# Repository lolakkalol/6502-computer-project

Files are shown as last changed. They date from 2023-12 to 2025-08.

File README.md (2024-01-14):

<!-- Improved compatibility of back to top link: See: https://github.com/lolakkalol/6502-computer-project/pull/73 -->

<!--
*** Thanks for checking out the Best-README-Template. If you have a suggestion
*** that would make this better, please fork the repo and create a pull request
*** or simply open an issue with the tag "enhancement".
*** Don't forget to give the project a star!
*** Thanks again! Now go create something AMAZING! :D
-->

<!-- PROJECT SHIELDS -->
<!--
*** I'm using markdown "reference style" links for readability.
*** Reference links are enclosed in brackets [ ] instead of parentheses ( ).
*** See the bottom of this document for the declaration of the reference variables
*** for contributors-url, forks-url, etc. This is an optional, concise syntax you may use.
*** https://www.markdownguide.org/basic-syntax/#reference-style-links
-->
[][contributors-url]
[][forks-url]
[][stars-url]
[][issues-url]
<!--[![MIT License][license-shield]][license-url]
[![LinkedIn][linkedin-shield]][linkedin-url]-->

<!-- PROJECT LOGO -->
<br />
<div align="center">
  <a href="https://github.com/lolakkalol/6502-computer-project">
    
  </a>

  <h3 align="center">6502 Computer Project</h3>

  <p align="center">
    A 6502-based computer project!
    <br />
    <a href="https://github.com/lolakkalol/6502-computer-project"><strong>Explore the docs »</strong></a>
    <br />
    <br />
    <a href="https://github.com/lolakkalol/6502-computer-project/tree/main/programs">View Demo Programs</a>
    ·
    <a href="https://github.com/lolakkalol/6502-computer-project/issues">Report Bug</a>
    ·
    <a href="https://github.com/lolakkalol/6502-computer-project/issues">Request Feature</a>
  </p>
</div>

<!-- TABLE OF CONTENTS -->
<details>
  <summary>Table of Contents</summary>
  <ol>
    <li>
      <a href="#about-the-project">About The Project</a>
      <ul>
        <li><a href="#built-with">Built With</a></li>
      </ul>
    </li>
    <li>
      <a href="#getting-started">Getting Started</a>
      <ul>
        <li><a href="#prerequisites">Prerequisites</a></li>
        <li><a href="#installation">Installation</a></li>
      </ul>
    </li>
    <li><a href="#usage">Usage</a></li>
    <li><a href="#roadmap">Roadmap</a></li>
    <li><a href="#contributing">Contributing</a></li>
    <li><a href="#license">License</a></li>
    <li><a href="#contact">Contact</a></li>
    <li><a href="#acknowledgments">Acknowledgments</a></li>
  </ol>
</details>

<!-- ABOUT THE PROJECT -->
## About The Project

[Product Name Screen Shot](https://example.com)

This project started thanks to [Ben Eater's](https://www.youtube.com/@BenEater) video series on his 6502-based computer, which is the basis for my project and learning experience.
The project has a very simple goal of me learning low-level embedded system development on hardware and software. To achieve this learning goal, a few project goals/milestones have been set up to steer the project in a satisfactory direction.
The computer should also not be a carbon copy of Ben Eater's computer to promote self-learning and delving into documentation and learning by doing. I believe you remember things better when you fail at something and, in the end, solve the problems that made you fail.

### Goals
These goals aim to create a 6502-based computer on a single PCB that can be expanded with modules later on.
- Learn "low-level" embedded computer architecture basics
  - Both hardware and software
- Build a 6502-based computer on a PCB which shall:
  - Be expandable, meaning you can add modules to it later (Some kind of expansion bus)
  - Output text console to a computer screen
  - Handle mouse and keyboard (USB/PS2 either or both)
  - Have serial communication capability
  - Load programs over serial into RAM (Maybe some kind of bootloader?)
  - Flash the program flash over some protocol
  - Some kind of operating system
- Try and avoid scope creep
- HAVE FUN!

<p align="right">(<a href="#readme-top">back to top</a>)</p>

### Built With
These are the currently used programs and frameworks used for building the project, for both software and hardware.

- [CA65, LD65](https://cc65.github.io/) for assembling, linking and relocating the code.
- [KiCad](https://www.kicad.org/) for designing the computer and its physical layout.
- [GNU Make](https://www.gnu.org/software/make/) for automating the build tasks of CC65 and LD65.

<p align="right">(<a href="#readme-top">back to top</a>)</p>

<!-- GETTING STARTED -->
## Getting Started

To get a local copy up and running follow these simple example steps.

### Prerequisites

* CC65 (Windows/Linux)
Download and install the cross-development package [CC65](https://github.com/cc65/cc65) (available for both Windows and Linux).

* GNU Utils (Windows)
Download `GNU make` and `CoreUtils` from https://gnuwin32.sourceforge.net/packages.html and add them to your path.

### Installation (Software)

1. Clone the repository
2. In `6502-computer-project/programs/<program name>/` simple run make
3. Flash the EEPROM using your choice of programmer

<p align="right">(<a href="#readme-top">back to top</a>)</p>

<!-- USAGE EXAMPLES -->
## Usage

This project currently has three different areas: Schematics and KiCad symbols, hardware debugger, and programs, each will be explained below.

### Schematics and KiCad symbols
Found in the folder `6502-and-friends` and `6502-schematic`, here the schematic over the computer, the custom symbols and PCB design can be found.

### Hardware debugger
Found, at the moment, in the folder `bus-sniffer`; this is simply a program for an Arduino Mega2560 sniffing and printing to the console the: Address bus, data buss and control bus.
It can also supply its own clock, which can be halted at the press of a button and send single clock pulses to support hardware debugging.

### Programs
Found in the folder `Programs`, contain all the currently constructed programs and a template for creating a new program.
Each program comes with its own make file specifying how it is to be built together with throughout commenting. 
All programs are written in 6502 assembly and most is created according to the specified template.

The template contain the following:
- `main.asm` Here is the main code.
- `lib.asm` Here, the supporting code should be put, such as sub-routines, following the example sub-routines structure.
- `start.asm` holds the start-up code and is already written in the template; it is responsible for initializing memory segments at startup.
- `makefile` Specifies how to build and link `main.asm`, `lib.asm` and `start.asm`.
- `target.cfg` Specifies the address space, segments, and their location in memory for the linker to us.

<p align="right">(<a href="#readme-top">back to top</a>)</p>

<!-- ROADMAP -->
## Roadmap
There are currently two main roadmaps, one for a Pi estimation program used to get familiar with the 6502 and another for the actual computer project.
For the Pi estimation program the computer seen in the current KiCad schematic is used.

### Pi estimation
- [ ] IEEE 754 Floating point arithmetic
  - [X] Addition/Subtraction
  - [ ] Multiplication
  - [ ] Division
  - [ ] (To be expanded upon if necessary)
- [ ] LCD printing
- [ ] Convert Floating point numbers to decimal
- [ ] Pi estimation algorithm
  - [ ] (To be expanded upon)

### 6502-based computer
- [ ] Decide desirable features
- [ ] Design schematic
  - [ ] Research chips needed
  - [ ] Plan address space
  - [ ] Create KiCad symbols for chips
  - [ ] Route connections between chips
  - [ ] (To be expanded upon)
- [ ] Operating system?

See the [open issues](https://github.com/lolakkalol/6502-computer-project/issues) for a full list of proposed features (and known issues).

<p align="right">(<a href="#readme-top">back to top</a>)</p>

## Micro documentation
Here a very small condenced documentation can be found only used as a quick reference.
The code is often commented so do not forget to look there.

### Memory map


### Floating point routines
The floating point routines are all commented on and explained in the code but have also been planned before implementation using a high-level flowchart in draw.io found below.

[Flowchart](https://drive.google.com/file/d/1zk0GJeMiMwG2__90PIV5DE1KcaoCTDiV/view?usp=sharing)

<!-- CONTRIBUTING -->
<!--## Contributing

Contributions are what make the open source community such an amazing place to learn, inspire, and create. Any contributions you make are **greatly appreciated**.

If you have a suggestion that would make this better, please fork the repo and create a pull request. You can also simply open an issue with the tag "enhancement".
Don't forget to give the project a star! Thanks again!

1. Fork the Project
2. Create your Feature Branch (`git checkout -b feature/AmazingFeature`)
3. Commit your Changes (`git commit -m 'Add some AmazingFeature'`)
4. Push to the Branch (`git push origin feature/AmazingFeature`)
5. Open a Pull Request

<p align="right">(<a href="#readme-top">back to top</a>)</p>-->

<!-- LICENSE -->
<!--## License

Distributed under the MIT License. See `LICENSE.txt` for more information.

<p align="right">(<a href="#readme-top">back to top</a>)</p>-->

<!-- CONTACT -->
## Contact

Alexander Stenlund -  alexander.stenlund@telia.com

Project Link: [https://github.com/lolakkalol/6502-computer-project](https://github.com/lolakkalol/6502-computer-project)

<p align="right">(<a href="#readme-top">back to top</a>)</p>

<!-- ACKNOWLEDGMENTS -->
## Acknowledgments

* [6502 Primer](https://wilsonminesco.com/6502primer/)
* [6502 forum](http://forum.6502.org/viewtopic.php?t=1064&start=105)
* [65SIB](http://forum.6502.org/viewtopic.php?t=1064&start=105)

<p align="right">(<a href="#readme-top">back to top</a>)</p>

<!-- MARKDOWN LINKS & IMAGES -->
<!-- https://www.markdownguide.org/basic-syntax/#reference-style-links -->
[contributors-shield]: https://img.shields.io/github/contributors/lolakkalol/6502-computer-project.svg?style=for-the-badge
[contributors-url]: https://github.com/lolakkalol/6502-computer-project/graphs/contributors
[forks-shield]: https://img.shields.io/github/forks/lolakkalol/6502-computer-project.svg?style=for-the-badge
[forks-url]: https://github.com/lolakkalol/6502-computer-project/network/members
[stars-shield]: https://img.shields.io/github/stars/lolakkalol/6502-computer-project.svg?style=for-the-badge
[stars-url]: https://github.com/lolakkalol/6502-computer-project/stargazers
[issues-shield]: https://img.shields.io/github/issues/lolakkalol/6502-computer-project.svg?style=for-the-badge
[issues-url]: https://github.com/lolakkalol/6502-computer-project/issues
[license-shield]: https://img.shields.io/github/license/lolakkalol/6502-computer-project.svg?style=for-the-badge
[license-url]: https://github.com/lolakkalol/6502-computer-project/blob/master/LICENSE.txt
[linkedin-shield]: https://img.shields.io/badge/-LinkedIn-black.svg?style=for-the-badge&logo=linkedin&colorB=555
[linkedin-url]: https://linkedin.com/in/othneildrew
[product-screenshot]: images/screenshot.png

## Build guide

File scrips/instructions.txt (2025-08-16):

ADC #Oper;69
ADC (ZP);72
ADC (ZP),Y;71
ADC (ZP,X);61
ADC Abs;6D
ADC Abs,X;7D
ADC Abs,Y;79
ADC ZP;65
ADC ZP,X;75
AND #Oper;29
AND (ZP);32
AND (ZP),Y;31
AND (ZP,X);21
AND Abs;2D
AND Abs,X;3D
AND Abs,Y;39
AND ZP;25
AND ZP,X;35
ASL A;0A
ASL Abs;0E
ASL Abs,X;1E
ASL ZP;6
ASL ZP,X;16
BBR0 Oper;0F
BBR1 Oper;1F
BBR2 Oper;2F
BBR3 Oper;3F
BBR4 Oper;4F
BBR5 Oper;5F
BBR6 Oper;6F
BBR7 Oper;7F
BBS0 Oper;8F
BBS1 Oper;9F
BBS2 Oper;AF
BBS3 Oper;BF
BBS4 Oper;CF
BBS5 Oper;DF
BBS6 Oper;EF
BBS7 Oper;FF
BCC Oper;90
BCS Oper;B0
BEQ Oper;F0
BIT #Oper;89
BIT Abs;2C
BIT Abs,X;3C
BIT ZP;24
BIT ZP,X;34
BMI Oper;30
BNE Oper;D0
BPL Oper;10
BRA Oper;80
BRK;0
BVC Oper;50
BVS Oper;70
CLC;18
CLD;D8
CLI;58
CLV;B8
CMP #Oper;C9
CMP (ZP);D2
CMP (ZP),Y;D1
CMP (ZP,X);C1
CMP Abs;CD
CMP Abs,X;DD
CMP Abs,Y;D9
CMP ZP;C5
CMP ZP;D5
CPX #Oper;E0
CPX Abs;EC
CPX ZP;E4
CPY #Oper;C0
CPY Abs;CC
CPY ZP;C4
DEA;3A
DEC Abs;CE
DEC Abs,X;DE
DEC ZP;C6
DEC ZP,X;D6
DEX;CA
DEY;88
EOR #Oper;49
EOR (ZP);52
EOR (ZP),Y;51
EOR (ZP,X);41
EOR Abs;4D
EOR Abs,X;5D
EOR Abs,Y;59
EOR ZP;45
EOR ZP,X;55
INA;1A
INC Abs;EE
INC Abs,X;FE
INC ZP;E6
INC ZP,X;F6
INX;E8
INY;C8
JMP (Abs);6C
JMP (Abs,X);7C
JMP Abs;4C
JSR Abs;20
LDA #Oper;A9
LDA (ZP);B2
LDA (ZP),Y;B1
LDA (ZP,X);A1
LDA Abs;AD
LDA Abs,X;BD
LDA Abs,Y;B9
LDA ZP;A5
LDA ZP,X;B5
LDX #Oper;A2
LDX Abs;AE
LDX Abs,Y;BE
LDX ZP;A6
LDX ZP,Y;B6
LDY #Oper;A0
LDY Abs;AC
LDY Abs,X;BC
LDY ZP;A4
LDY ZP,X;B4
LSR A;4A
LSR Abs;4E
LSR Abs,X;5E
LSR ZP;46
LSR ZP,X;56
NOP;EA
ORA #Oper;9
ORA (ZP);12
ORA (ZP),Y;11
ORA (ZP,X);1
ORA Abs;0D
ORA Abs,X;1D
ORA Abs,Y;19
ORA ZP;5
ORA ZP,X;15
PHA;48
PHX;DA
PHY;5A
PLA;68
PLX;FA
PLY;7A
ROL A;2A
ROL Abs;2E
ROL Abs,X;3E
ROL ZP;26
ROL ZP,X;36
ROR A;6A
ROR Abs;6E
ROR Abs,X;7E
ROR ZP;66
ROR ZP,X;76
RTI;40
RTS;60
SBC #Oper;E9
SBC (ZP);F2
SBC (ZP),Y;F1
SBC (ZP,X);E1
SBC Abs;ED
SBC Abs,X;FD
SBC Abs,Y;F9
SBC ZP;E5
SBC ZP,X;F5
SEC;38
SED;F8
SEI;78
STA (ZP);92
STA (ZP),Y;91
STA (ZP,X);81
STA Abs;8D
STA Abs,X;9D
STA Abs,Y;99
STA ZP;85
STA ZP,X;95
STX Abs;8E
STX ZP;86
STX ZP,Y;96
STY Abs;8C
STY ZP;84
STY ZP,X;94
STZ Abs;9C
STZ Abs,X;9E
STZ ZP;64
STZ ZP,X;74
TAX;AA
TAY;A8
TRB Abs;1C
TRB ZP;14
TSB Abs;0C
TSB ZP;4
TSX;BA
TXA;8A
TXS;9A
TYA;98

case 0x$1:
    sprintf(buf, "$2");
    break;

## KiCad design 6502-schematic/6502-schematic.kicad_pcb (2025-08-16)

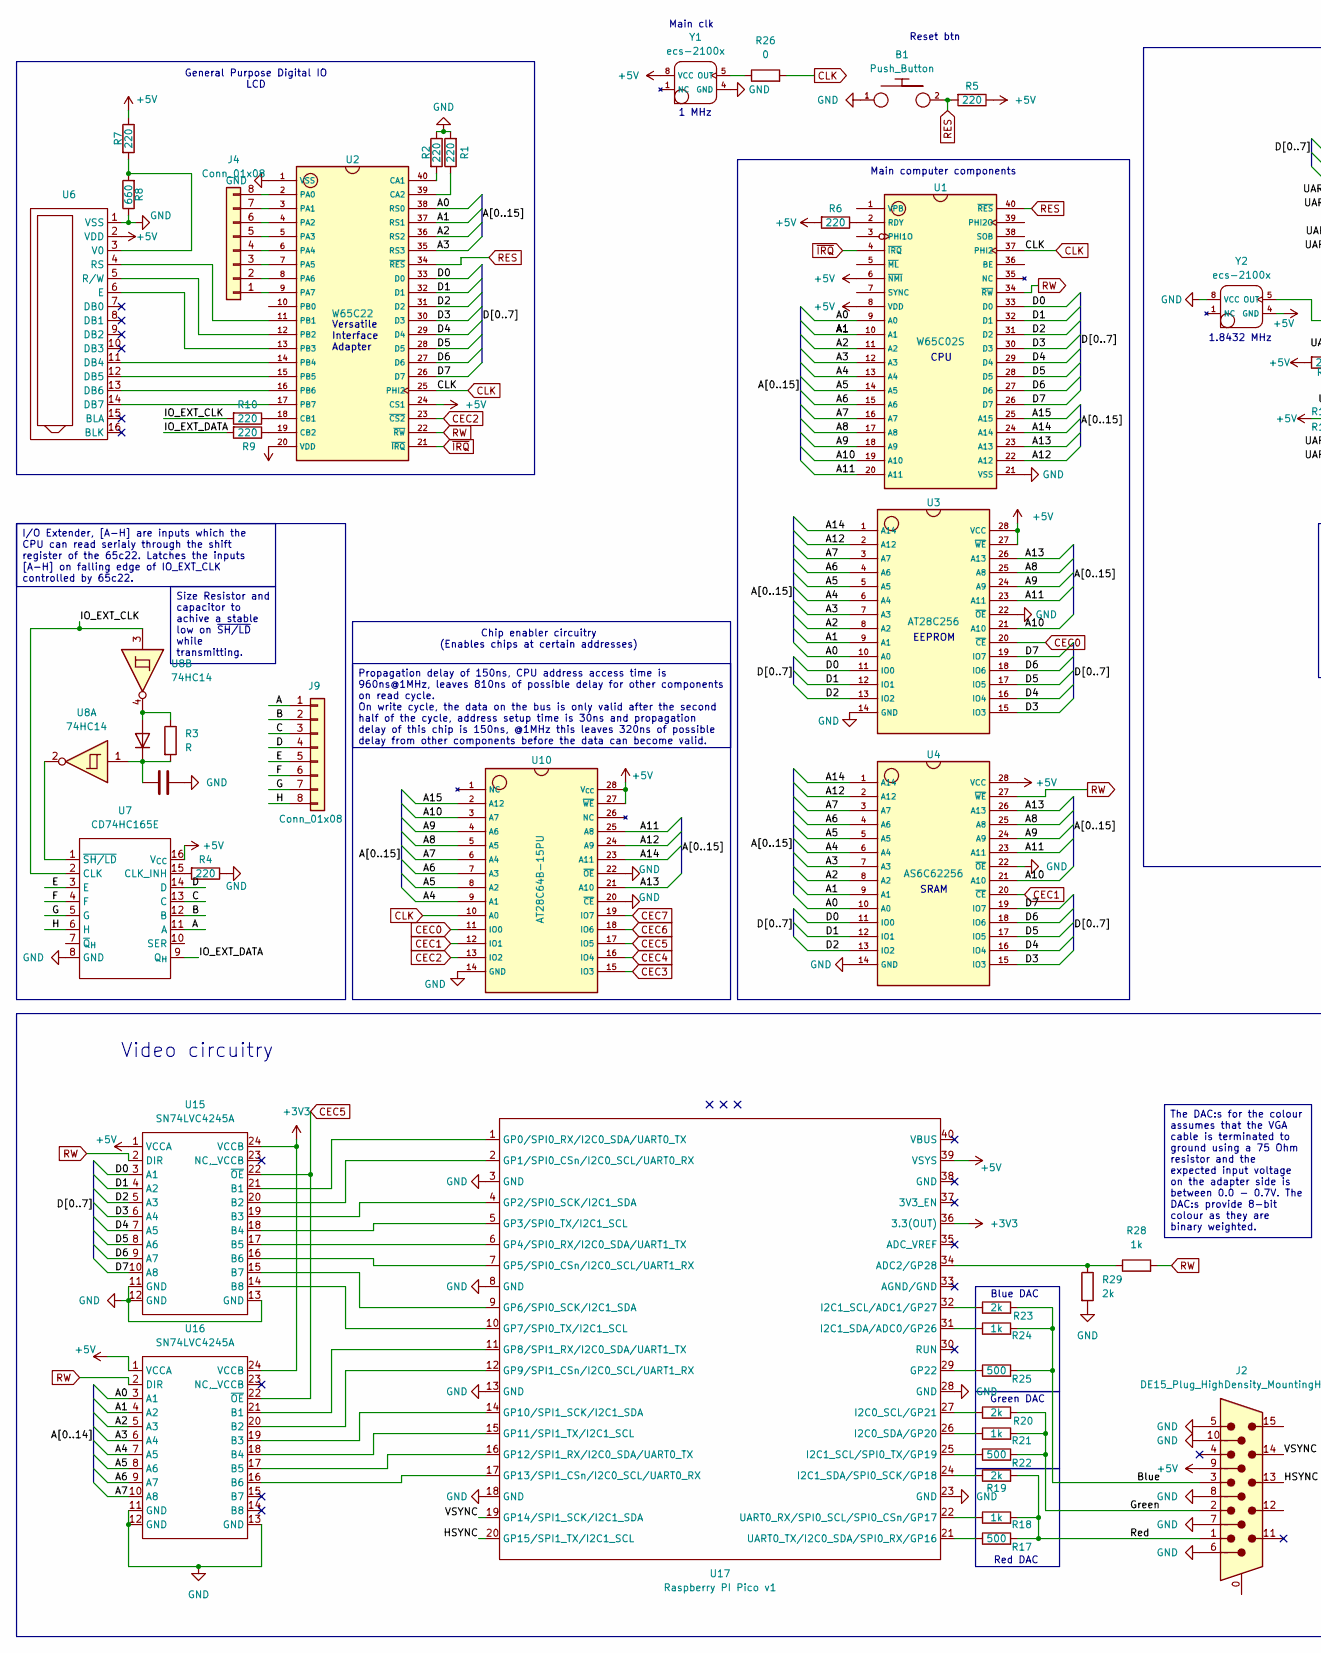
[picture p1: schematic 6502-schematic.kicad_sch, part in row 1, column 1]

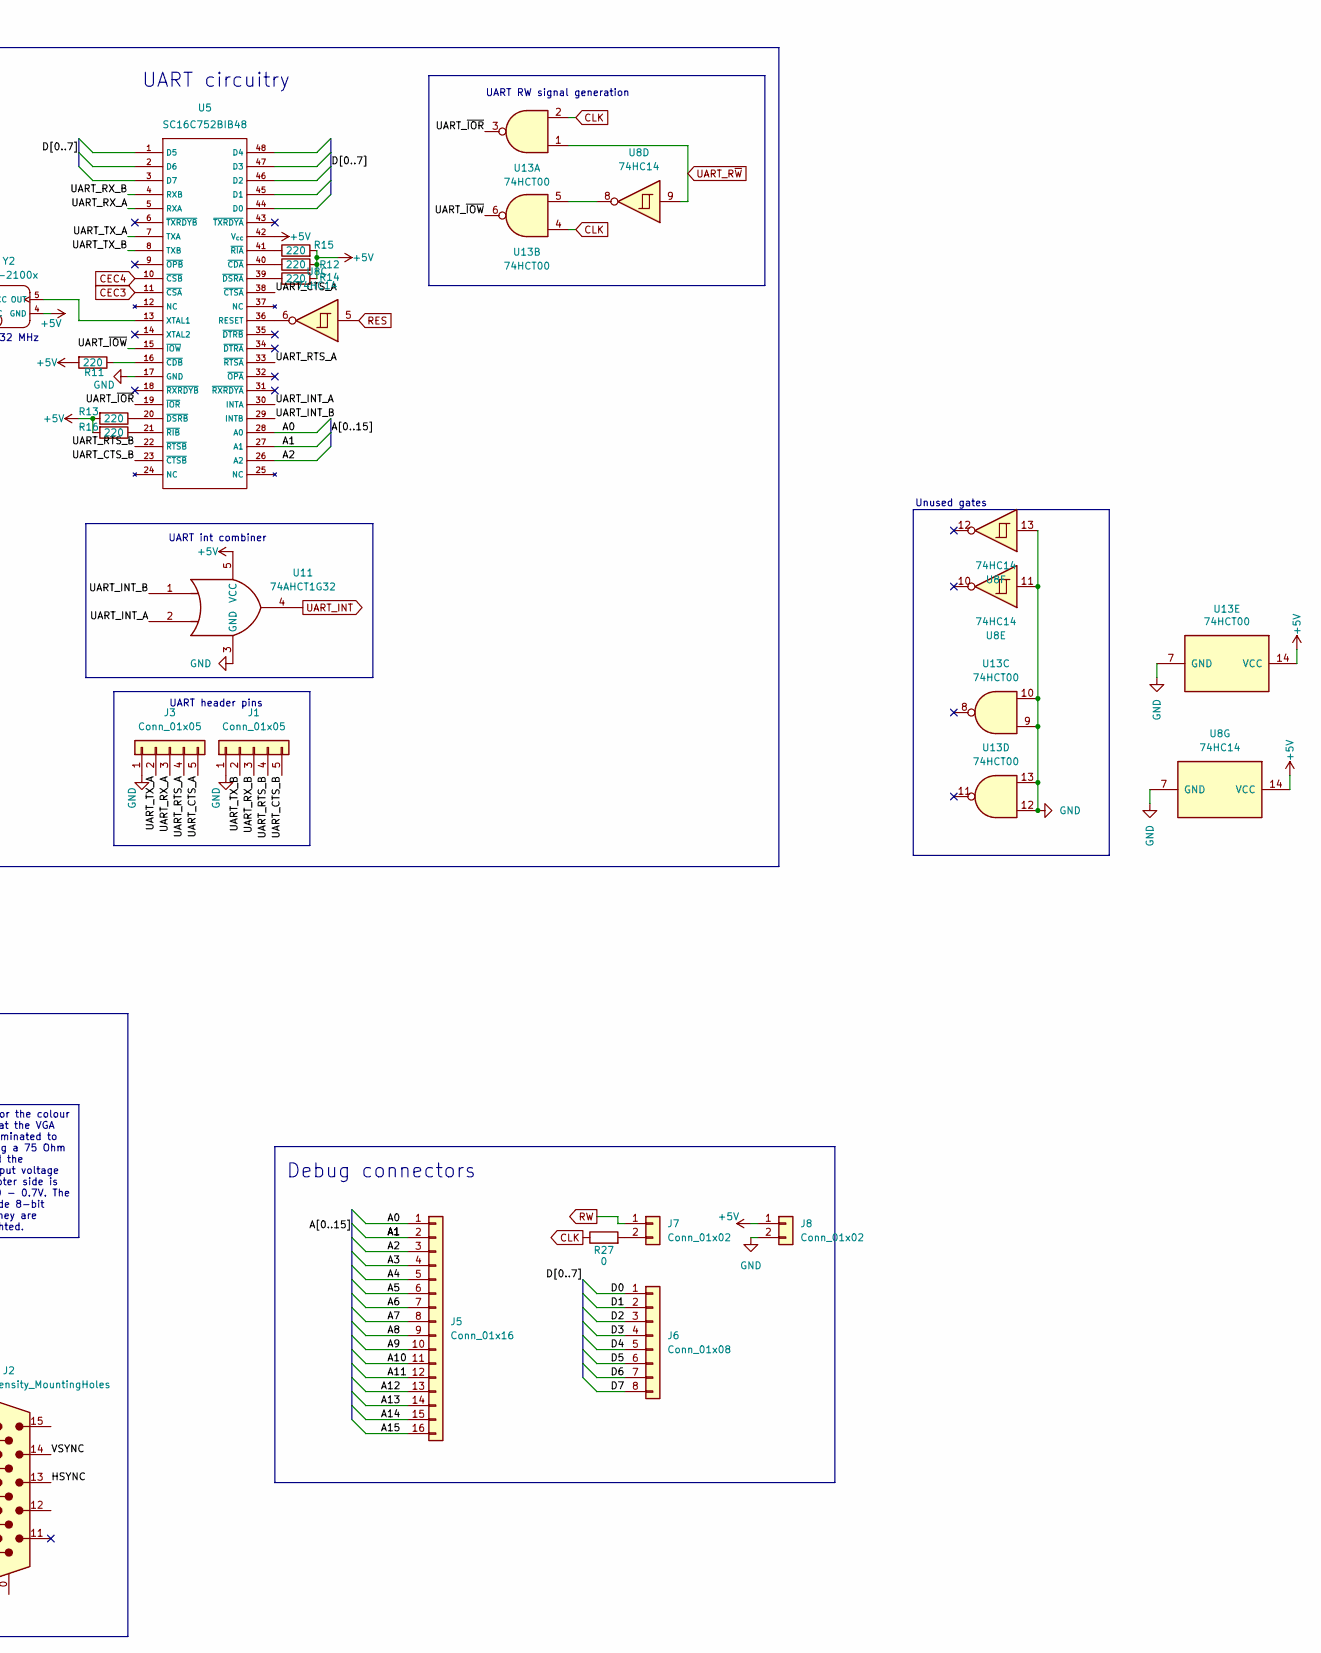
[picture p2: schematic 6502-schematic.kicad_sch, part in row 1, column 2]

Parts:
B1: Push_Button; KSA_Tactile_SPST
C1: C; C_Disc_D9.0mm_W5.0mm_P10.00mm
D1: D; D_5W_P10.16mm_Horizontal
J1, J3: Conn_01x05; PinHeader_1x05_P2.54mm_Vertical
J2: DE15_Plug_HighDensity_MountingHoles; PinHeader_2x08_P2.54mm_Vertical
J4, J6, J9: Conn_01x08; PinHeader_1x08_P2.54mm_Vertical
J5: Conn_01x16; PinHeader_1x16_P2.54mm_Vertical
J7, J8: Conn_01x02; PinHeader_1x02_P2.54mm_Vertical
R1, R2, R4, R5, R6, R7, R9, R10, R11, R12, R13, R14, R15, R16: 220; R_Axial_DIN0204_L3.6mm_D1.6mm_P2.54mm_Vertical
R3: R; R_Axial_DIN0204_L3.6mm_D1.6mm_P2.54mm_Vertical
R8: 660; R_Axial_DIN0204_L3.6mm_D1.6mm_P2.54mm_Vertical
R17, R22, R25: 500; R_Axial_DIN0204_L3.6mm_D1.6mm_P2.54mm_Vertical
R18, R21, R24, R28: 1k; R_Axial_DIN0204_L3.6mm_D1.6mm_P2.54mm_Vertical
R19, R20, R23, R29: 2k; R_Axial_DIN0204_L3.6mm_D1.6mm_P2.54mm_Vertical
R26, R27: 0; R_0805_2012Metric_Pad1.20x1.40mm_HandSolder
U1: W65C02S; DIP-40_W15.24mm_LongPads
U2: W65C22; DIP-40_W15.24mm_LongPads
U3: AT28C256; DIP-28_W15.24mm_LongPads
U4: AS6C62256; DIP-28_W15.24mm_LongPads
U5: SC16C752BIB48; LQFP-48_7x7mm_P0.5mm
U6: PinHeader_1x16_P2.54mm_Vertical
U7: CD74HC165E; DIP-16_W7.62mm_LongPads
U8: 74HC14; CERDIP-14_W7.62mm_SideBrazed_LongPads
U10: AT28C64B-15PU; DIP-28_W15.24mm_LongPads
U11: 74AHCT1G32; SOT-23-5_HandSoldering
U13: 74HCT00; DIP-14_W7.62mm_LongPads
U15, U16: SN74LVC4245A; SOIC-24W_7.5x15.4mm_P1.27mm
U17: Raspberry PI Pico v1; Raspberry_PI_Pico_Socket
Y1, Y2: ecs-2100x; ECS-2100X

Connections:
+3V3: U15.24 (VCCB), U16.24 (VCCB), U17.36 (3.3(OUT))
+5V: J2.9, J8.1, R5.1, R6.2, R7.1, R11.2, R12.2, R13.2, R14.2, R15.2, R16.2, U1.6 (~NMI), U1.8 (VDD), U2.20 (VDD), U2.24 (CS1), U3.27 (~WE), U3.28 (VCC), U4.28 (VCC), U5.42 (V_{cc}), U6.2 (VDD), U7.16 (V_{CC}), U8.14 (VCC), U10.27 (~WE), U10.28 (V_{CC}), U11.5 (VCC), U13.14 (VCC), U15.1 (VCCA), U16.1 (VCCA), U17.39 (VSYS), Y1.8 (VCC), Y2.4 (GND)
/A: J9.1, U7.11 (A)
/A0: J5.1, U1.9 (A0), U2.38 (RS0), U3.10 (A0), U4.10 (A0), U5.28 (A0), U16.3 (A1)
/A1: J5.2, U1.10 (A1), U2.37 (RS1), U3.9 (A1), U4.9 (A1), U5.27 (A1), U16.4 (A2)
/A2: J5.3, U1.11 (A2), U2.36 (RS2), U3.8 (A2), U4.8 (A2), U5.26 (A2), U16.5 (A3)
/A3: J5.4, U1.12 (A3), U2.35 (RS3), U3.7 (A3), U4.7 (A3), U16.6 (A4)
/A4: J5.5, U1.13 (A4), U3.6 (A4), U4.6 (A4), U10.9 (A1), U16.7 (A5)
/A5: J5.6, U1.14 (A5), U3.5 (A5), U4.5 (A5), U10.8 (A2), U16.8 (A6)
/A6: J5.7, U1.15 (A6), U3.4 (A6), U4.4 (A6), U10.7 (A3), U16.9 (A7)
/A7: J5.8, U1.16 (A7), U3.3 (A7), U4.3 (A7), U10.6 (A4), U16.10 (A8)
/A8: J5.9, U1.17 (A8), U3.25 (A8), U4.25 (A8), U10.5 (A5)
/A9: J5.10, U1.18 (A9), U3.24 (A9), U4.24 (A9), U10.4 (A6)
/A10: J5.11, U1.19 (A10), U3.21 (A10), U4.21 (A10), U10.3 (A7)
/A11: J5.12, U1.20 (A11), U3.23 (A11), U4.23 (A11), U10.25 (A8)
/A12: J5.13, U1.22 (A12), U3.2 (A12), U4.2 (A12), U10.24 (A9)
/A13: J5.14, U1.23 (A13), U3.26 (A13), U4.26 (A13), U10.21 (A10)
/A14: J5.15, U1.24 (A14), U3.1 (A14), U4.1 (A14), U10.23 (A11)
/A15: J5.16, U1.25 (A15), U10.2 (A12)
/B: J9.2, U7.12 (B)
/Blue: J2.3, R23.2, R24.2, R25.2
/C: J9.3, U7.13 (C)
/D: J9.4, U7.14 (D)
/D0: J6.1, U1.33 (D0), U2.33 (D0), U3.11 (IO0), U4.11 (IO0), U15.3 (A1)
/D1: J6.2, U1.32 (D1), U2.32 (D1), U3.12 (IO1), U4.12 (IO1), U15.4 (A2)
/D2: J6.3, U1.31 (D2), U2.31 (D2), U3.13 (IO2), U4.13 (IO2), U15.5 (A3)
/D3: J6.4, U1.30 (D3), U2.30 (D3), U3.15 (IO3), U4.15 (IO3), U15.6 (A4)
/D4: J6.5, U1.29 (D4), U2.29 (D4), U3.16 (IO4), U4.16 (IO4), U15.7 (A5)
/D5: J6.6, U1.28 (D5), U2.28 (D5), U3.17 (IO5), U4.17 (IO5), U15.8 (A6)
/D6: J6.7, U1.27 (D6), U2.27 (D6), U3.18 (IO6), U4.18 (IO6), U15.9 (A7)
/D7: J6.8, U1.26 (D7), U2.26 (D7), U3.19 (IO7), U4.19 (IO7), U15.10 (A8)
/E: J9.5, U7.3 (E)
/F: J9.6, U7.4 (F)
/G: J9.7, U7.5 (G)
/Green: J2.2, R20.2, R21.2, R22.2
/H: J9.8, U7.6 (H)
/HSYNC: J2.13, U17.20 (GP15/SPI1_TX/I2C1_SCL)
/IO_EXT_CLK: R10.2, U7.2 (CLK), U8.3
/IO_EXT_DATA: R9.2, U7.9 (Q_{H})
/Red: J2.1, R17.2, R18.2, R19.2
/UART_CTS_A: J3.5, U5.38 (~CTSA)
/UART_CTS_B: J1.5, U5.23 (~CTSB)
/UART_INT_A: U5.30 (INTA), U11.2
/UART_INT_B: U5.29 (INTB), U11.1
/UART_RTS_A: J3.4, U5.33 (~RTSA)
/UART_RTS_B: J1.4, U5.22 (~RTSB)
/UART_RX_A: J3.3, U5.5 (RXA)
/UART_RX_B: J1.3, U5.4 (RXB)
/UART_TX_A: J3.2, U5.7 (TXA)
/UART_TX_B: J1.2, U5.8 (TXB)
/UART_~IOR: U5.19 (~IOR), U13.3
/UART_~IOW: U5.15 (~IOW), U13.6
/VSYNC: J2.14, U17.19 (GP14/SPI1_SCK/I2C1_SDA)
CEC0: U3.20 (~CE), U10.11 (IO0)
CEC1: U4.20 (~CE), U10.12 (IO1)
CEC2: U2.23 (~CS2), U10.13 (IO2)
CEC3: U5.11 (~CSA), U10.15 (IO3)
CEC4: U5.10 (~CSB), U10.16 (IO4)
CEC5: U10.17 (IO5), U15.22 (~OE), U16.22 (~OE)
CEC6: U10.18 (IO6)
CEC7: U10.19 (IO7)
CLK: R26.2, R27.1, U1.37 (PHI2), U2.25 (PHI2), U10.10 (A0), U13.2, U13.4
GND: B1.1, C1.2, J1.1, J2.5, J2.6, J2.7, J2.8, J2.10, J3.1, J8.2, R1.2, R2.1, R4.1, R8.1, R29.2, U1.21 (VSS), U2.1 (VSS), U3.14 (GND), U3.22 (~OE), U4.14 (GND), U4.22 (~OE), U5.17 (GND), U6.1 (VSS), U7.8 (GND), U8.7 (GND), U8.11, U8.13, U10.14 (GND), U10.20 (~CE), U10.22 (~OE), U11.3 (GND), U13.7 (GND), U13.9, U13.10, U13.12, U13.13, U15.11 (GND), U15.12 (GND), U15.13 (GND), U16.11 (GND), U16.12 (GND), U16.13 (GND), U17.3 (GND), U17.8 (GND), U17.13 (GND), U17.18 (GND), U17.23 (GND), U17.28 (GND), Y1.4 (GND), Y2.8 (VCC)
unnamed: D1.2 (A), R3.1, U8.4
unnamed: C1.1, D1.1 (K), R3.2, U8.1
unnamed: J4.1, U2.9 (PA7)
unnamed: J4.2, U2.8 (PA6)
unnamed: J4.3, U2.7 (PA5)
unnamed: J4.4, U2.6 (PA4)
unnamed: J4.5, U2.5 (PA3)
unnamed: J4.6, U2.4 (PA2)
unnamed: J4.7, U2.3 (PA1)
unnamed: J4.8, U2.2 (PA0)
unnamed: J7.2, R27.2
unnamed: R6.1, U1.2 (RDY)
unnamed: R2.2, U2.40 (CA1)
unnamed: R1.1, U2.39 (CA2)
unnamed: R10.1, U2.18 (CB1)
unnamed: R9.1, U2.19 (CB2)
unnamed: U2.11 (PB1), U6.4 (RS)
unnamed: U2.12 (PB2), U6.5 (R/W)
unnamed: U2.13 (PB3), U6.6 (E)
unnamed: U2.14 (PB4), U6.11 (DB4)
unnamed: U2.15 (PB5), U6.12 (DB5)
unnamed: U2.16 (PB6), U6.13 (DB6)
unnamed: U2.17 (PB7), U6.14 (DB7)
unnamed: U5.36 (RESET), U8.6
unnamed: U5.13 (XTAL1), Y2.5 (OUT)
unnamed: R12.1, U5.40 (~CDA)
unnamed: R11.1, U5.16 (~CDB)
unnamed: R14.1, U5.39 (~DSRA)
unnamed: R13.1, U5.20 (~DSRB)
unnamed: R15.1, U5.41 (~RIA)
unnamed: R16.1, U5.21 (~RIB)
unnamed: R7.2, R8.2, U6.3 (V0)
unnamed: R4.2, U7.15 (CLK_INH)
unnamed: U7.1 (~SH/LD), U8.2
unnamed: U8.8, U13.5
unnamed: U15.21 (B1), U17.1 (GP0/SPI0_RX/I2C0_SDA/UART0_TX)
unnamed: U15.20 (B2), U17.2 (GP1/SPI0_CSn/I2C0_SCL/UART0_RX)
unnamed: U15.19 (B3), U17.4 (GP2/SPI0_SCK/I2C1_SDA)
unnamed: U15.18 (B4), U17.5 (GP3/SPI0_TX/I2C1_SCL)
unnamed: U15.17 (B5), U17.6 (GP4/SPI0_RX/I2C0_SDA/UART1_TX)
unnamed: U15.16 (B6), U17.7 (GP5/SPI0_CSn/I2C0_SCL/UART1_RX)
unnamed: U15.15 (B7), U17.9 (GP6/SPI0_SCK/I2C1_SDA)
unnamed: U15.14 (B8), U17.10 (GP7/SPI0_TX/I2C1_SCL)
unnamed: U16.21 (B1), U17.11 (GP8/SPI1_RX/I2C0_SDA/UART1_TX)
unnamed: U16.20 (B2), U17.12 (GP9/SPI1_CSn/I2C0_SCL/UART1_RX)
unnamed: U16.19 (B3), U17.14 (GP10/SPI1_SCK/I2C1_SDA)
unnamed: U16.18 (B4), U17.15 (GP11/SPI1_TX/I2C1_SCL)
unnamed: U16.17 (B5), U17.16 (GP12/SPI1_RX/I2C0_SDA/UART0_TX)
unnamed: U16.16 (B6), U17.17 (GP13/SPI1_CSn/I2C0_SCL/UART0_RX)
unnamed: R28.1, R29.1, U17.34 (ADC2/GP28)
unnamed: R25.1, U17.29 (GP22)
unnamed: R20.1, U17.27 (I2C0_SCL/GP21)
unnamed: R21.1, U17.26 (I2C0_SDA/GP20)
unnamed: R23.1, U17.32 (I2C1_SCL/ADC1/GP27)
unnamed: R22.1, U17.25 (I2C1_SCL/SPI0_TX/GP19)
unnamed: R24.1, U17.31 (I2C1_SDA/ADC0/GP26)
unnamed: R19.1, U17.24 (I2C1_SDA/SPI0_SCK/GP18)
unnamed: R18.1, U17.22 (UART0_RX/SPI0_SCL/SPI0_CSn/GP17)
unnamed: R17.1, U17.21 (UART0_TX/I2C0_SDA/SPI0_RX/GP16)
unnamed: R26.1, Y1.5 (OUT)
RES: B1.2, R5.2, U1.40 (~RES), U2.34 (~RES), U8.5
RW: J7.1, R28.2, U1.34 (~RW), U2.22 (~RW), U4.27 (~WE), U15.2 (DIR), U16.2 (DIR)
UART_INT: U11.4
UART_R~W: U8.9, U13.1
~IRQ: U1.4 (~IRQ), U2.21 (~IRQ)

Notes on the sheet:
UART int combiner
Blue DAC
Chip enabler circuitry (Enables chips at certain addresses)
Red DAC
Green DAC
UART circuitry
UART header pins
Unused gates
1 MHz
Reset btn
Versatile Interface Adapter
CPU
Main clk
Main computer components
1.8432 MHz
SRAM
UART RW signal generation
General Purpose Digital IO LCD
Debug connectors
Video circuitry
EEPROM
I/O Extender, [A-H] are inputs which the CPU can read serialy through the shift register of the 65c22. Latches the inputs [A-H] on falling edge of IO_EXT_CLK controlled by 65c22.
Size Resistor and capacitor to achive a stable low on ~{SH/LD} while transmitting.
Propagation delay of 150ns, CPU address access time is 960ns@1MHz, leaves 810ns of possible delay for other components on read cycle. On write cycle, the data on the bus is only valid after the second half of the cycle, address setup time is 30ns and propagation delay of this chip is 150ns, @1MHz t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
The DAC:s for the colour assumes that the VGA cable is terminated to ground using a 75 Ohm resistor and the expected input voltage on the adapter side is between 0.0 - 0.7V. The DAC:s provide 8-bit colour as they are binary weighted.

Board: 2 copper layers, 57 parts (0 on the bottom side), 125 nets, no tracks yet.

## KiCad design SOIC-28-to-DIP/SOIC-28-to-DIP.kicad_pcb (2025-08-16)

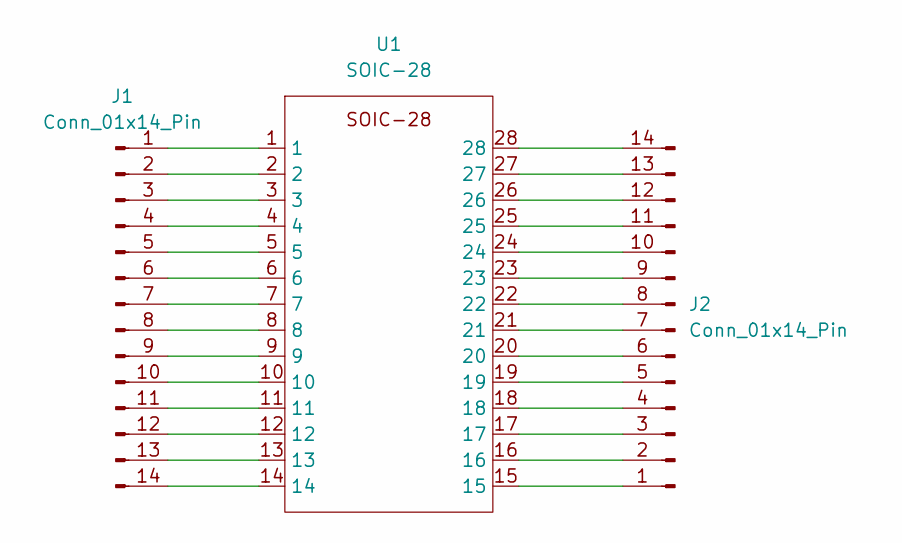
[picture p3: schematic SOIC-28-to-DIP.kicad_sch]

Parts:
J1, J2: Conn_01x14_Pin; PinHeader_1x14_P2.54mm_Vertical
U1: SOIC-28; SOIC-28W_7.5x18.7mm_P1.27mm

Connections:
unnamed: J1.1, U1.1
unnamed: J1.2, U1.2
unnamed: J1.3, U1.3
unnamed: J1.4, U1.4
unnamed: J1.5, U1.5
unnamed: J1.6, U1.6
unnamed: J1.7, U1.7
unnamed: J1.8, U1.8
unnamed: J1.9, U1.9
unnamed: J1.10, U1.10
unnamed: J1.11, U1.11
unnamed: J1.12, U1.12
unnamed: J1.13, U1.13
unnamed: J1.14, U1.14
unnamed: J2.1, U1.15
unnamed: J2.2, U1.16
unnamed: J2.3, U1.17
unnamed: J2.4, U1.18
unnamed: J2.5, U1.19
unnamed: J2.6, U1.20
unnamed: J2.7, U1.21
unnamed: J2.8, U1.22
unnamed: J2.9, U1.23
unnamed: J2.10, U1.24
unnamed: J2.11, U1.25
unnamed: J2.12, U1.26
unnamed: J2.13, U1.27
unnamed: J2.14, U1.28

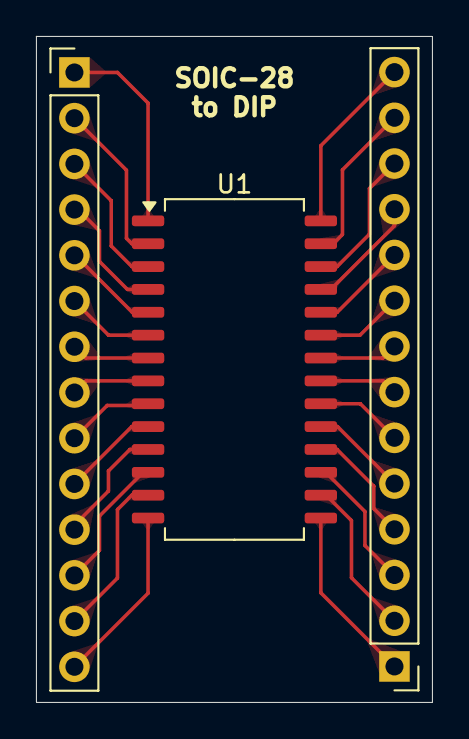
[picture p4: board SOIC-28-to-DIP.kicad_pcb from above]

Board: 2 copper layers, 22.0 x 37.0 mm, 3 parts (0 on the bottom side), 28 nets.

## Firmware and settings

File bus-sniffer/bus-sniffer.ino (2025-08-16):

//uint8_t adress_lines = {};
//uint8_t data_lines   = {};

uint8_t rw_pin    = 37;
uint8_t clk_pin   = 31;
uint8_t pause_pin = 33; // Not an actual pin in the computer but used to temporarily halt the clock

// Trigger
uint8_t triggered = 0;
uint8_t t_event = 1;
uint8_t event_count = 0;

bool clk = false;

void nextCycle() {
  digitalWrite(clk_pin, LOW);
  digitalWrite(clk_pin, HIGH);
  digitalWrite(clk_pin, LOW);
}

void getBinaryRep(char* buf, uint16_t data) {
  for(uint8_t i = 0; i < 16; i++)
    buf[i] = (data >> i) & 0x0001 ? '1' : '0';

  buf[16] = '\0';
}

void getBinaryRep(char* buf, uint8_t data) {
  for(uint8_t i = 0; i < 8; i++)
    buf[i] = (data >> i) & 0x01 ? '1' : '0';

  buf[8] = '\0';
}

void decodeOP(char* buf, uint8_t op) {
  switch (op) {
    case 0x69:
        sprintf(buf, "ADC #Oper");
        break;
    case 0x72:
        sprintf(buf, "ADC (ZP)");
        break;
    case 0x71:
        sprintf(buf, "ADC (ZP),Y");
        break;
    case 0x61:
        sprintf(buf, "ADC (ZP,X)");
        break;
    case 0x6D:
        sprintf(buf, "ADC Abs");
        break;
    case 0x7D:
        sprintf(buf, "ADC Abs,X");
        break;
    case 0x79:
        sprintf(buf, "ADC Abs,Y");
        break;
    case 0x65:
        sprintf(buf, "ADC ZP");
        break;
    case 0x75:
        sprintf(buf, "ADC ZP,X");
        break;
    case 0x29:
        sprintf(buf, "AND #Oper");
        break;
    case 0x32:
        sprintf(buf, "AND (ZP)");
        break;
    case 0x31:
        sprintf(buf, "AND (ZP),Y");
        break;
    case 0x21:
        sprintf(buf, "AND (ZP,X)");
        break;
    case 0x2D:
        sprintf(buf, "AND Abs");
        break;
    case 0x3D:
        sprintf(buf, "AND Abs,X");
        break;
    case 0x39:
        sprintf(buf, "AND Abs,Y");
        break;
    case 0x25:
        sprintf(buf, "AND ZP");
        break;
    case 0x35:
        sprintf(buf, "AND ZP,X");
        break;
    case 0x0A:
        sprintf(buf, "ASL A");
        break;
    case 0x0E:
        sprintf(buf, "ASL Abs");
        break;
    case 0x1E:
        sprintf(buf, "ASL Abs,X");
        break;
    case 0x6:
        sprintf(buf, "ASL ZP");
        break;
    case 0x16:
        sprintf(buf, "ASL ZP,X");
        break;
    case 0x0F:
        sprintf(buf, "BBR0 Oper");
        break;
    case 0x1F:
        sprintf(buf, "BBR1 Oper");
        break;
    case 0x2F:
        sprintf(buf, "BBR2 Oper");
        break;
    case 0x3F:
        sprintf(buf, "BBR3 Oper");
        break;
    case 0x4F:
        sprintf(buf, "BBR4 Oper");
        break;
    case 0x5F:
        sprintf(buf, "BBR5 Oper");
        break;
    case 0x6F:
        sprintf(buf, "BBR6 Oper");
        break;
    case 0x7F:
        sprintf(buf, "BBR7 Oper");
        break;
    case 0x8F:
        sprintf(buf, "BBS0 Oper");
        break;
    case 0x9F:
        sprintf(buf, "BBS1 Oper");
        break;
    case 0xAF:
        sprintf(buf, "BBS2 Oper");
        break;
    case 0xBF:
        sprintf(buf, "BBS3 Oper");
        break;
    case 0xCF:
        sprintf(buf, "BBS4 Oper");
        break;
    case 0xDF:
        sprintf(buf, "BBS5 Oper");
        break;
    case 0xEF:
        sprintf(buf, "BBS6 Oper");
        break;
    case 0xFF:
        sprintf(buf, "BBS7 Oper");
        break;
    case 0x90:
        sprintf(buf, "BCC Oper");
        break;
    case 0xB0:
        sprintf(buf, "BCS Oper");
        break;
    case 0xF0:
        sprintf(buf, "BEQ Oper");
        break;
    case 0x89:
        sprintf(buf, "BIT #Oper");
        break;
    case 0x2C:
        sprintf(buf, "BIT Abs");
        break;
    case 0x3C:
        sprintf(buf, "BIT Abs,X");
        break;
    case 0x24:
        sprintf(buf, "BIT ZP");
        break;
    case 0x34:
        sprintf(buf, "BIT ZP,X");
        break;
    case 0x30:
        sprintf(buf, "BMI Oper");
        break;
    case 0xD0:
        sprintf(buf, "BNE Oper");
        break;
    case 0x10:
        sprintf(buf, "BPL Oper");
        break;
    case 0x80:
        sprintf(buf, "BRA Oper");
        break;
    case 0x0:
        sprintf(buf, "BRK");
        break;
    case 0x50:
        sprintf(buf, "BVC Oper");
        break;
    case 0x70:
        sprintf(buf, "BVS Oper");
        break;
    case 0x18:
        sprintf(buf, "CLC");
        break;
    case 0xD8:
        sprintf(buf, "CLD");
        break;
    case 0x58:
        sprintf(buf, "CLI");
        break;
    case 0xB8:
        sprintf(buf, "CLV");
        break;
    case 0xC9:
        sprintf(buf, "CMP #Oper");
        break;
    case 0xD2:
        sprintf(buf, "CMP (ZP)");
        break;
    case 0xD1:
        sprintf(buf, "CMP (ZP),Y");
        break;
    case 0xC1:
        sprintf(buf, "CMP (ZP,X)");
        break;
    case 0xCD:
        sprintf(buf, "CMP Abs");
        break;
    case 0xDD:
        sprintf(buf, "CMP Abs,X");
        break;
    case 0xD9:
        sprintf(buf, "CMP Abs,Y");
        break;
    case 0xC5:
        sprintf(buf, "CMP ZP");
        break;
    case 0xD5:
        sprintf(buf, "CMP ZP");
        break;
    case 0xE0:
        sprintf(buf, "CPX #Oper");
        break;
    case 0xEC:
        sprintf(buf, "CPX Abs");
        break;
    case 0xE4:
        sprintf(buf, "CPX ZP");
        break;
    case 0xC0:
        sprintf(buf, "CPY #Oper");
        break;
    case 0xCC:
        sprintf(buf, "CPY Abs");
        break;
    case 0xC4:
        sprintf(buf, "CPY ZP");
        break;
    case 0x3A:
        sprintf(buf, "DEA");
        break;
    case 0xCE:
        sprintf(buf, "DEC Abs");
        break;
    case 0xDE:
        sprintf(buf, "DEC Abs,X");
        break;
    case 0xC6:
        sprintf(buf, "DEC ZP");
        break;
    case 0xD6:
        sprintf(buf, "DEC ZP,X");
        break;
    case 0xCA:
        sprintf(buf, "DEX");
        break;
    case 0x88:
        sprintf(buf, "DEY");
        break;
    case 0x49:
        sprintf(buf, "EOR #Oper");
        break;
    case 0x52:
        sprintf(buf, "EOR (ZP)");
        break;
    case 0x51:
        sprintf(buf, "EOR (ZP),Y");
        break;
    case 0x41:
        sprintf(buf, "EOR (ZP,X)");
        break;
    case 0x4D:
        sprintf(buf, "EOR Abs");
        break;
    case 0x5D:
        sprintf(buf, "EOR Abs,X");
        break;
    case 0x59:
        sprintf(buf, "EOR Abs,Y");
        break;
    case 0x45:
        sprintf(buf, "EOR ZP");
        break;
    case 0x55:
        sprintf(buf, "EOR ZP,X");
        break;
    case 0x1A:
        sprintf(buf, "INA");
        break;
    case 0xEE:
        sprintf(buf, "INC Abs");
        break;
    case 0xFE:
        sprintf(buf, "INC Abs,X");
        break;
    case 0xE6:
        sprintf(buf, "INC ZP");
        break;
    case 0xF6:
        sprintf(buf, "INC ZP,X");
        break;
    case 0xE8:
        sprintf(buf, "INX");
        break;
    case 0xC8:
        sprintf(buf, "INY");
        break;
    case 0x6C:
        sprintf(buf, "JMP (Abs)");
        break;
    case 0x7C:
        sprintf(buf, "JMP (Abs,X)");
        break;
    case 0x4C:
        sprintf(buf, "JMP Abs");
        break;
    case 0x20:
        sprintf(buf, "JSR Abs");
        break;
    case 0xA9:
        sprintf(buf, "LDA #Oper");
        break;
    case 0xB2:
        sprintf(buf, "LDA (ZP)");
        break;
    case 0xB1:
        sprintf(buf, "LDA (ZP),Y");
        break;
    case 0xA1:
        sprintf(buf, "LDA (ZP,X)");
        break;
    case 0xAD:
        sprintf(buf, "LDA Abs");
        break;
    case 0xBD:
        sprintf(buf, "LDA Abs,X");
        break;
    case 0xB9:
        sprintf(buf, "LDA Abs,Y");
        break;
    case 0xA5:
        sprintf(buf, "LDA ZP");
        break;
    case 0xB5:
        sprintf(buf, "LDA ZP,X");
        break;
    case 0xA2:
        sprintf(buf, "LDX #Oper");
        break;
    case 0xAE:
        sprintf(buf, "LDX Abs");
        break;
    case 0xBE:
        sprintf(buf, "LDX Abs,Y");
        break;
    case 0xA6:
        sprintf(buf, "LDX ZP");
        break;
    case 0xB6:
        sprintf(buf, "LDX ZP,Y");
        break;
    case 0xA0:
        sprintf(buf, "LDY #Oper");
        break;
    case 0xAC:
        sprintf(buf, "LDY Abs");
        break;
    case 0xBC:
        sprintf(buf, "LDY Abs,X");
        break;
    case 0xA4:
        sprintf(buf, "LDY ZP");
        break;
    case 0xB4:
        sprintf(buf, "LDY ZP,X");
        break;
    case 0x4A:
        sprintf(buf, "LSR A");
        break;
    case 0x4E:
        sprintf(buf, "LSR Abs");
        break;
    case 0x5E:
        sprintf(buf, "LSR Abs,X");
        break;
    case 0x46:
        sprintf(buf, "LSR ZP");
        break;
    case 0x56:
        sprintf(buf, "LSR ZP,X");
        break;
    case 0xEA:
        sprintf(buf, "NOP");
        break;
    case 0x9:
        sprintf(buf, "ORA #Oper");
        break;
    case 0x12:
        sprintf(buf, "ORA (ZP)");
        break;
    case 0x11:
        sprintf(buf, "ORA (ZP),Y");
        break;
    case 0x1:
        sprintf(buf, "ORA (ZP,X)");
        break;
    case 0x0D:
        sprintf(buf, "ORA Abs");
        break;
    case 0x1D:
        sprintf(buf, "ORA Abs,X");
        break;
    case 0x19:
        sprintf(buf, "ORA Abs,Y");
        break;
    case 0x5:
        sprintf(buf, "ORA ZP");
        break;
    case 0x15:
        sprintf(buf, "ORA ZP,X");
        break;
    case 0x48:
        sprintf(buf, "PHA");
        break;
    case 0xDA:
        sprintf(buf, "PHX");
        break;
    case 0x5A:
        sprintf(buf, "PHY");
        break;
    case 0x68:
        sprintf(buf, "PLA");
        break;
    case 0xFA:
        sprintf(buf, "PLX");
        break;
    case 0x7A:
        sprintf(buf, "PLY");
        break;
    case 0x2A:
        sprintf(buf, "ROL A");
        break;
    case 0x2E:
        sprintf(buf, "ROL Abs");
        break;
    case 0x3E:
        sprintf(buf, "ROL Abs,X");
        break;
    case 0x26:
        sprintf(buf, "ROL ZP");
        break;
    case 0x36:
        sprintf(buf, "ROL ZP,X");
        break;
    case 0x6A:
        sprintf(buf, "ROR A");
        break;
    case 0x6E:
        sprintf(buf, "ROR Abs");
        break;
    case 0x7E:
        sprintf(buf, "ROR Abs,X");
        break;
    case 0x66:
        sprintf(buf, "ROR ZP");
        break;
    case 0x76:
        sprintf(buf, "ROR ZP,X");
        break;
    case 0x40:
        sprintf(buf, "RTI");
        break;
    case 0x60:
        sprintf(buf, "RTS");
        break;
    case 0xE9:
        sprintf(buf, "SBC #Oper");
        break;
    case 0xF2:
        sprintf(buf, "SBC (ZP)");
        break;
    case 0xF1:
        sprintf(buf, "SBC (ZP),Y");
        break;
    case 0xE1:
        sprintf(buf, "SBC (ZP,X)");
        break;
    case 0xED:
        sprintf(buf, "SBC Abs");
        break;
    case 0xFD:
        sprintf(buf, "SBC Abs,X");
        break;
    case 0xF9:
        sprintf(buf, "SBC Abs,Y");
        break;
    case 0xE5:
        sprintf(buf, "SBC ZP");
        break;
    case 0xF5:
        sprintf(buf, "SBC ZP,X");
        break;
    case 0x38:
        sprintf(buf, "SEC");
        break;
    case 0xF8:
        sprintf(buf, "SED");
        break;
    case 0x78:
        sprintf(buf, "SEI");
        break;
    case 0x92:
        sprintf(buf, "STA (ZP)");
        break;
    case 0x91:
        sprintf(buf, "STA (ZP),Y");
        break;
    case 0x81:
        sprintf(buf, "STA (ZP,X)");
        break;
    case 0x8D:
        sprintf(buf, "STA Abs");
        break;
    case 0x9D:
        sprintf(buf, "STA Abs,X");
        break;
    case 0x99:
        sprintf(buf, "STA Abs,Y");
        break;
    case 0x85:
        sprintf(buf, "STA ZP");
        break;
    case 0x95:
        sprintf(buf, "STA ZP,X");
        break;
    case 0x8E:
        sprintf(buf, "STX Abs");
        break;
    case 0x86:
        sprintf(buf, "STX ZP");
        break;
    case 0x96:
        sprintf(buf, "STX ZP,Y");
        break;
    case 0x8C:
        sprintf(buf, "STY Abs");
        break;
    case 0x84:
        sprintf(buf, "STY ZP");
        break;
    case 0x94:
        sprintf(buf, "STY ZP,X");
        break;
    case 0x9C:
        sprintf(buf, "STZ Abs");
        break;
    case 0x9E:
        sprintf(buf, "STZ Abs,X");
        break;
    case 0x64:
        sprintf(buf, "STZ ZP");
        break;
    case 0x74:
        sprintf(buf, "STZ ZP,X");
        break;
    case 0xAA:
        sprintf(buf, "TAX");
        break;
    case 0xA8:
        sprintf(buf, "TAY");
        break;
    case 0x1C:
        sprintf(buf, "TRB Abs");
        break;
    case 0x14:
        sprintf(buf, "TRB ZP");
        break;
    case 0x0C:
        sprintf(buf, "TSB Abs");
        break;
    case 0x4:
        sprintf(buf, "TSB ZP");
        break;
    case 0xBA:
        sprintf(buf, "TSX");
        break;
    case 0x8A:
        sprintf(buf, "TXA");
        break;
    case 0x9A:
        sprintf(buf, "TXS");
        break;
    case 0x98:
        sprintf(buf, "TYA");
        break;
    default:
      sprintf(buf, "UNKNOWN");
      break;
     
  }
}

void setup() {
  Serial.begin(115200);

  // Setup; address pins
  for (uint8_t i = 24; i <= 52; i+=2) {
    pinMode(i, INPUT);
  }
    
  // Setup; data pins
  for (uint8_t i = 39; i <= 53; i+=2)
    pinMode(i, INPUT);

  // Setup; rest of pins
  pinMode(rw_pin, INPUT);
  pinMode(clk_pin, OUTPUT);
  pinMode(pause_pin, INPUT);
}

uint16_t address = 0x0000;
uint8_t  data    = 0x00;

char buf[50];

void loop() {
  // Read address bus
  for (uint8_t i = 22; i <= 52; i+=2) {
    address = address >> 1;
    address |= digitalRead(i) << 15;
  }
  
  // Read data bus
  for (uint8_t i = 39; i <= 53; i+=2) {
    data = data >> 1;
    data |= digitalRead(i) << 7;
  }

  Serial.println("-------------------------------");
  Serial.println("               0123456789ABCDEF");

  // Print and format address
  sprintf(buf, "Addr: 0x%04X : \0", address);
  Serial.print(buf);
  
  getBinaryRep(buf, address);
  Serial.println(buf);

  // Print and format data
  sprintf(buf, "Data: 0x%02X   : \0", data);
  Serial.print(buf);

  getBinaryRep(buf, data);
  Serial.println(buf);

  sprintf(buf, "OP: ");
  Serial.print(buf);
  decodeOP(buf, data);
  Serial.println(buf);

  sprintf(buf, "R/W: %c\0", digitalRead(rw_pin) ? 'R' : 'W');
  Serial.println(buf);

  sprintf(buf, "Clk: %c", clk ? 'H' : 'L');
  Serial.println(buf);

  while (digitalRead(pause_pin) == 0)
    delay(100);
  
  clk = !clk;
  digitalWrite(clk_pin, clk ? HIGH : LOW);
  //nextCycle();
  delay(200);
  
}

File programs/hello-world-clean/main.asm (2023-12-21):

; Author: Alexander Stenlund
; Description: Writes the text "Hello, world!" to an LCD screen. It does this 
; though a memory mapped 65c22 VIA using both ports A and B. The LCD is 
; initilised to 8 bit mode and communicated with in a parallell bus on 
; port A and B.

.segment "CODE"

; Text to write to LCD
strHello: .asciiz "Hello, world!"
lenHello: .byte .STRLEN("Hello, world!")

; VIA Register addresses
;DDRA = $6003
DDRB = $6002
;IORA = $6001
IORB = $6000

; *************************
; *   SET UP 4-bit mode   *
; *************************
start:
JSR setup_up_LCD


; *******************
; * Write to screen *
; *******************

; Loop index
LDX #0

; 1  2  4  8 10  20  40  80
; NC RS RW E PB4 PB5 PB6 PB7

; Write string strHello to screen
writeLoop:
    ; Send first half of command (Upper char bytes)
    LDA strHello, X ; Load the character at address acc + X
    AND #$F0 ; Set all lower bits to zero
    ORA #$02 ; Set RS pin
    JSR command_LCD

    ; Send first half of command (Lower char bytes)
    LDA strHello, X ; Load the character at address acc + X
    ASL ; Shift the lower 4 bits up to the higher 4
    ASL
    ASL
    ASL
    ORA #$02 ; Set RS pin
    JSR command_LCD

    INX
    CPX lenHello
    BNE writeLoop

inf_loop: JMP inf_loop ; If at end we loop

; *******************
; *   Sub-routines  *
; *******************

setup_up_LCD:
; Set DDRB to output
LDA #$FF
STA DDRB

; Function set
LDA #$20 ; pin PB5
JSR command_LCD

; Function set
JSR command_LCD ; Repeat previous
JSR command_LCD ; Repeat previous

; Display on/off control
LDA #$00
JSR command_LCD

LDA #$E0 ; pins PB5 PB6 PB7
JSR command_LCD

; Entry mode set
LDA #$00
JSR command_LCD

LDA #$60 ; pins PB5 PB6
JSR command_LCD

RTS

; This sub-routine sends whatever data is in the 
; accumalator to the LCD.
command_LCD:
PHA

STA IORB ; Might be able to remove this instruction, test!
ORA #$08 ; pin E
STA IORB
LDA #$00 ; Setting all data to 0 should be fine...
STA IORB

PLA

JSR delay

RTS

delay:
PHA ; Save the acumalator
TXA ; Save index X in acumalator

LDX #$FF      ; 2
    loop:
    DEX       ; 2
    CPX #$0   ; 2
    BNE loop  ; 2

TAX ; Transer index X from acumalator
PLA ; Pull acumalator from stack
RTS

; 1  2  4  8 10  20  40  80
; NC RS RW E PB4 PB5 PB6 PB7

; Sets 6502 zeroflag if the busy flag from the LCD is set
; Not working :(
get_LCD_BF:

; Set data pins to inputs zero their register
LDA #$0F
STA DDRB
LDA #$4 ; Set pin RW

; Read busy flag
LDA IORB ; Will also get that pin RW is SET!!
AND #$80 ; PB7
CMP #$80 

; Set zero flag if BF set


; Set data on bus to zero

; Change PB4-7 to output

RTS

.segment "PC_START"
.WORD start

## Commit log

2023-12-18 Added two hello world programs, one clean with loop and one less clean with everything being sequential
    [target.cfg]
2023-12-18 Added KiCad lock files to be ignored
2023-12-20 Changed LCD interface and code to 4-bit mode
    [6502-schematic.kicad_sch]
2023-12-21 Added project template for easier starting projects
    [target.cfg]
2023-12-22 Expanded the template project to include the segments: DATA, BSS and LOAD. Seperated the reset vector calculation into a seperate .asm file
    [target.cfg]
2023-12-22 Added comment structure to use
    [target.cfg]
2023-12-22 Added loading routine for the DATA section in the LOAD section
    [target.cfg]
2023-12-22 Added RODATA section
    [target.cfg]
2023-12-26 First attempt at 32 bit floting point arithmetic
    [target.cfg]
2024-01-01 Removed no longer compatible sub-routines
    [lib.asm]
2024-01-13 Extended a branch instruction to jump more than 127 bytes. Fixed Negate two's complement to do so correctly
    [lib.asm]
2024-01-13 Fixed Is exponent 1? to actualy compare against 1 instead of 0
    [lib.asm]
2024-01-13 Added a jump to when result was zero to skip handling of sub-normal numbers
    [lib.asm]
2025-08-16 A lot of changes...
    Re drew the schematic, now contains an extra EEPROM which handles address glue logic.
    arduino debugger now decodes instructions on the databus
    Some new scripts which generate the address map for the new EEPROM gluelogic
    [6502-schematic.kicad_pcb, 6502-schematic.kicad_sch, SOIC-28-to-DIP.kicad_pcb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]
2025-08-16 Finished schematic
    Finished wiring up Raspberry pico up to the databus
    Added debug connectors
    set the footprint of all symbols
    Started with layout
    [6502-schematic.kicad_pcb, 6502-schematic.kicad_sch]
